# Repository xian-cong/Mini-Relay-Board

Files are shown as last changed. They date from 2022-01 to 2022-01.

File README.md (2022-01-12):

# Mini Relay Board
### Functions
This relay board is designed to be as small as possible using KiCAD to perform functions:
```
  1. Relay Switch Function (250VAC/30VDC rated voltage, 3A-5A rated current)
  2. Power Supply (5V, up to 2A) for microcontroller (e.g. Jetson Nano, Raspberry Pi, Arduino...)
  3. Push Button Input with Kill Function (i.e. IC kills the power if push button is pressed ~20secs)
  4. General Output pin (3.3V, up to 10mA) for LED/indicators
  5. SMD LED Indicator for Relay
  ```
  
### Components
Components & Datasheets can be found [here](https://github.com/xian-cong/mini-relay-board/blob/main/Components%20%26%20Datasheet.txt).

### Board Schematic
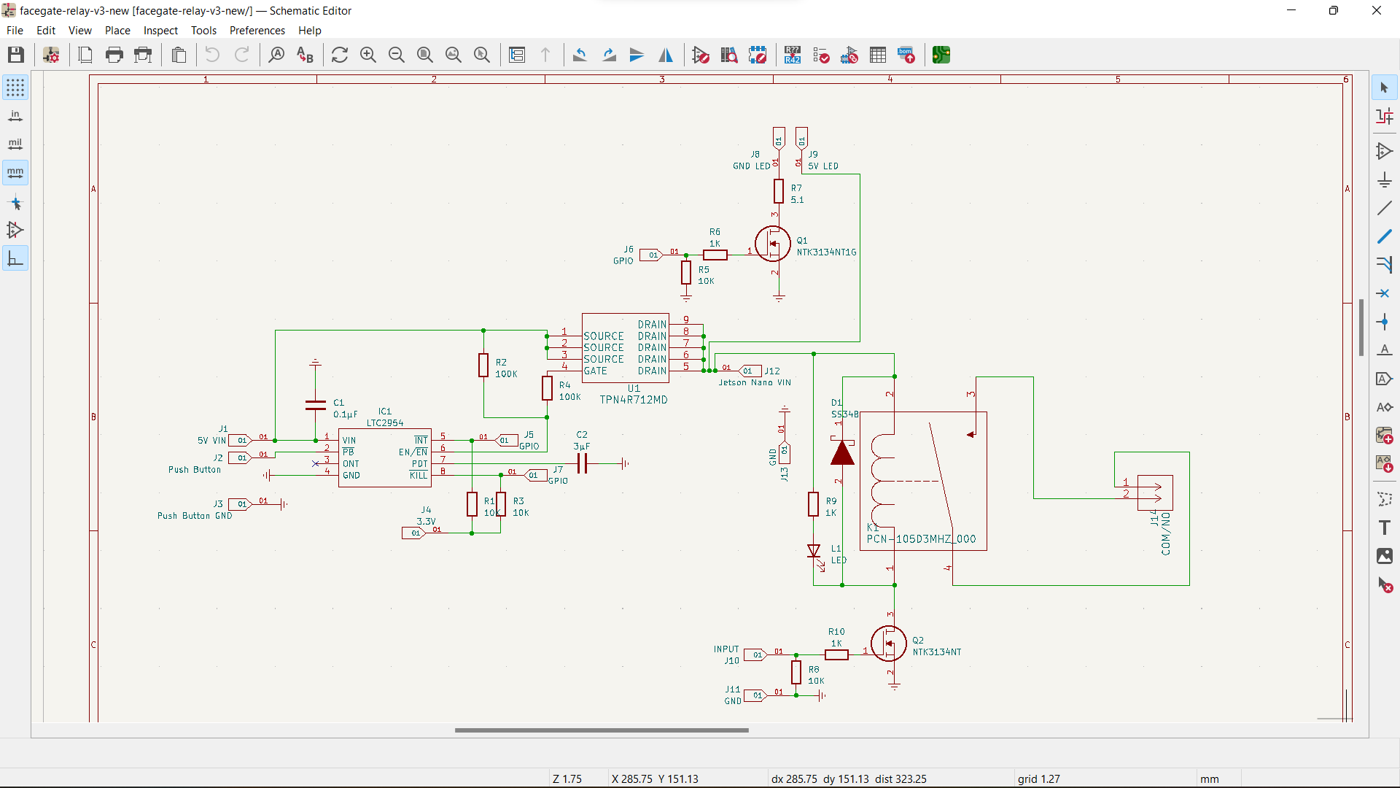
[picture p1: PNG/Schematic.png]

 
### Board Layout
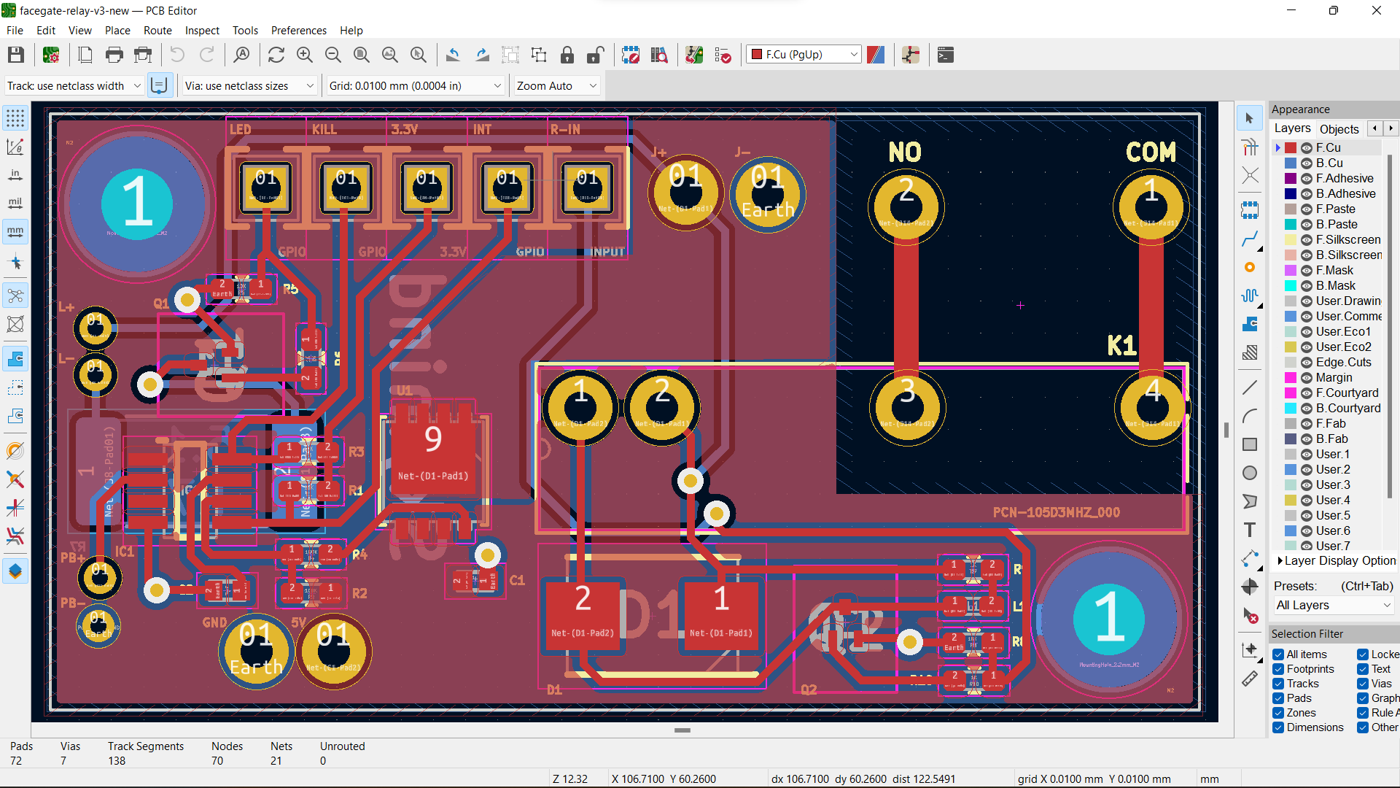
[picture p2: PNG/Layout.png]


### 3D View of Board
**Top View** <br />
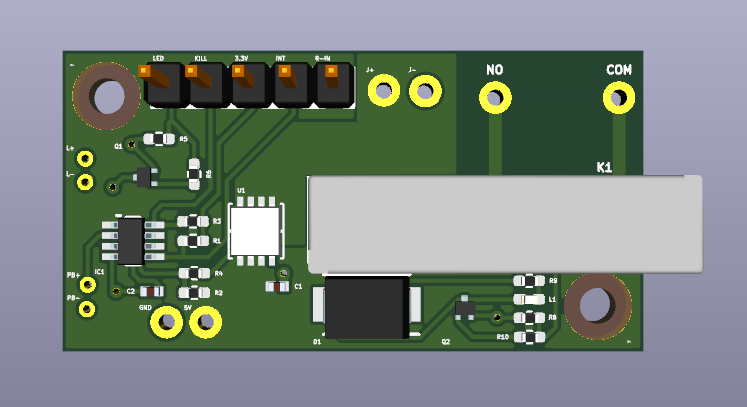
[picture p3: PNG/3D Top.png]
 <br />
**Isometric View** <br />
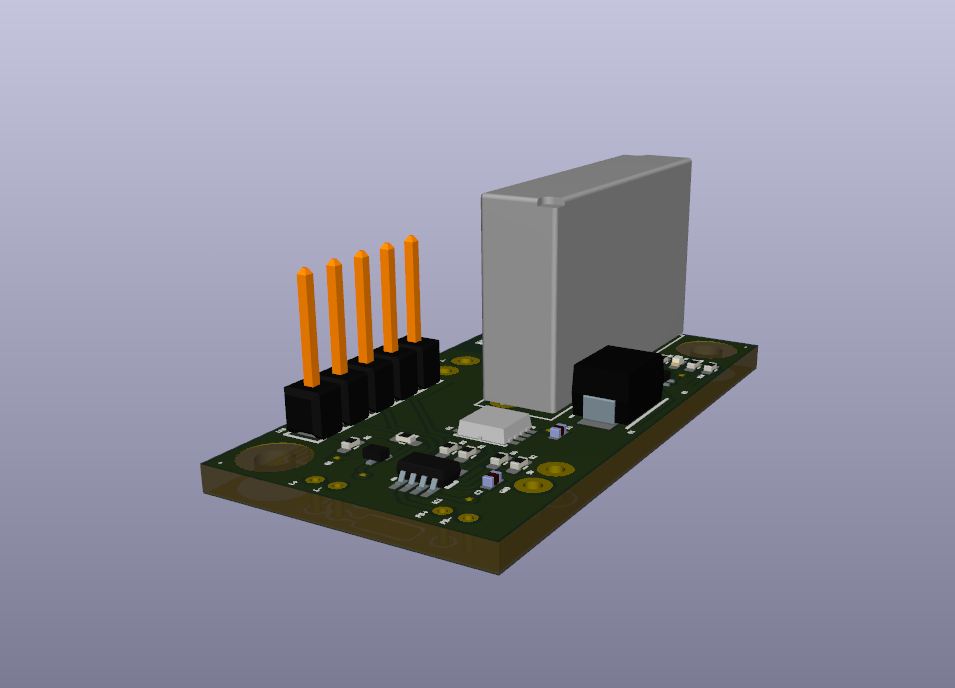
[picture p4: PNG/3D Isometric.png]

 
### Deployment View of Board
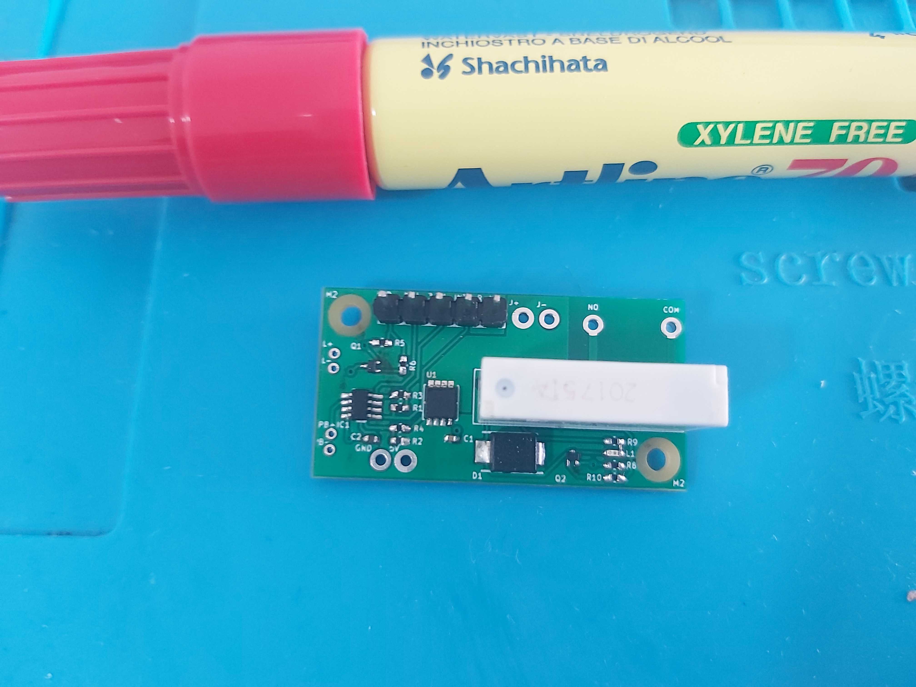
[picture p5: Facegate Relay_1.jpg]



### Board without Components


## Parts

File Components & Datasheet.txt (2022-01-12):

Relay:
https://www.digikey.my/product-detail/en/te-connectivity-potter-brumfield-relays/PCN-105D3MHZ-000/PCN-105D3MHZ000-ND/1427537
Datasheet: 
https://www.te.com/commerce/DocumentDelivery/DDEController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

Mosfet(N):
https://www.digikey.my/product-detail/en/on-semiconductor/NTK3134NT5G/2156-NTK3134NT5G-OS-ND/13457296

LED:
https://www.digikey.my/product-detail/en/kingbright/APHHS1005CGCK/754-1101-2-ND/1747499

Diode:
https://www.digikey.my/product-detail/en/mdd/SS34B/3372-SS34BTR-ND/14288057

ON/OFF IC:
https://www.analog.com/media/en/technical-documentation/data-sheets/2954fb.pdf

Mosfet(P):
https://www.digikey.my/product-detail/en/toshiba-semiconductor-and-storage/TPN4R712MD-L1Q/TPN4R712MDL1QCT-ND/5323105

Capacitor 0.1uF:
https://www.digikey.my/product-detail/en/kemet/C0402C104K7PAC7867/399-14871-1-ND/7382420

Capacitor 3uF:
https://www.digikey.my/product-detail/en/taiyo-yuden/AMK105BJ335MV-F/587-2236-6-ND/2003027

LED resistor:
https://www.digikey.my/product-detail/en/panasonic-electronic-components/ERJ-2GEJ5R1X/P5-1JCT-ND/282381
1k resistor:
https://www.digikey.my/product-detail/en/yageo/RC0402JR-071KL/311-1-0KJRCT-ND/729355

10k resistor:
https://www.digikey.my/product-detail/en/yageo/RC0402JR-0710KL/311-10KJRCT-ND/729365

100k resistor:
https://www.digikey.my/product-detail/en/yageo/RC0402FR-07100KL/311-100KLRCT-ND/729473

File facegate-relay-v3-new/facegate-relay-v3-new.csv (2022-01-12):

Id | Designator | Package | Quantity | Designation | Supplier and ref
1 | NO | ED120&slash_2DS | 1 | COM
2 | R4,R6 | R_0402_1005Metric | 2 | 100K
3 | C2 | CAPC1005X55N | 1 | 3μF
4 | K1 | PCN-105D3MHZ_000 | 1 | PCN-105D3MHZ_000
5 | Q1 | NTK3134NT1G | 1 | NTK3134NT
6 | C1 | CAPC1005X55N | 1 | 0.1μF
7 | R5,R3 | R_0402_1005Metric | 2 | 10K
8 | R7,R2,R1 | R_0402_1005Metric | 3 | 1K
9 | D1 | DIOM5336X320N | 1 | SS34B
10 | L1 | LED_0402_1005Metric | 1 | LED
11 | PB | SAMTEC_MTMM-101-06-S-S-200 | 1 | Push Button
12 | J-VIN | SAMTEC_MTMM-101-06-S-S-200 | 1 | Jetson Nano VIN
13 | Q2 | NTK3134NT1G | 1 | NTK3134NT1G
14 | U1 | TPN4R712MD | 1 | TPN4R712MD
15 | IC1 | SOT65P280X100-8N | 1 | LTC2954
16 | KILL,LED,INT | SAMTEC_MTMM-101-06-S-S-200 | 3 | GPIO
17 | 3.3V | SAMTEC_MTMM-101-06-S-S-200 | 1 | 3.3V
18 | 5V-IN | SAMTEC_MTMM-101-06-S-S-200 | 1 | 5V VIN
19 | LED | SAMTEC_MTMM-101-06-S-S-200 | 1 | 3.3V LED
20 | M2,M2 | MountingHole_2.2mm_M2 | 2 | MountingHole_2.2mm_M2
21 | 5V-GND,GND | SAMTEC_MTMM-101-06-S-S-200 | 2 | GND
22 |  |  | 1
23 | R-IN | SAMTEC_MTMM-101-06-S-S-200 | 1 | INPUT
24 | 5V | SAMTEC_MTMM-101-06-S-S-200 | 1 | 5V/VCC

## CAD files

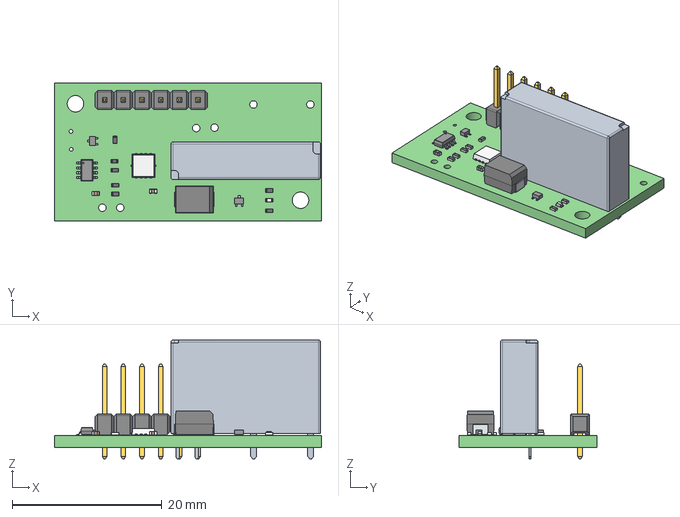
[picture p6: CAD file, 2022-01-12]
facegate-relay-v3-new/facegate-board.step
35.7 x 18.5 x 15.9 mm

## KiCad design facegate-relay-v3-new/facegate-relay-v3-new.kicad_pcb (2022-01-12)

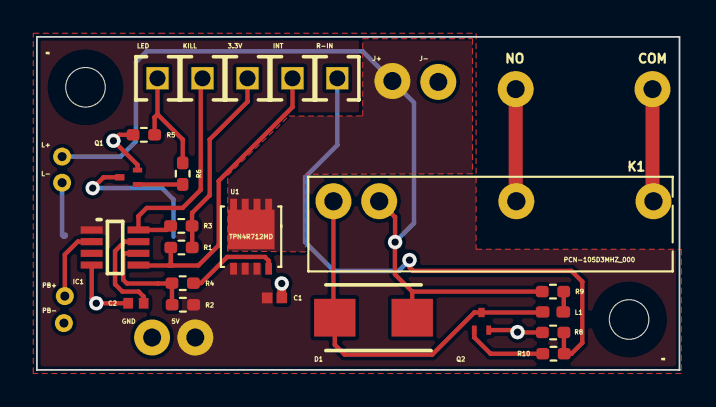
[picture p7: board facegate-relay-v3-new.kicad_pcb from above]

Board: 2 copper layers, 35.7 x 18.5 mm, 35 parts (1 on the bottom side), 20 nets.

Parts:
3.3V: 3.3V; SAMTEC_MTMM-101-06-S-S-200
5V: 5V VIN; SAMTEC_MTMM-101-06-S-S-200
C1: 0.1μF; CAPC1005X55N
C2: 3μF; CAPC1005X55N
D1: SS34B; DIOM5336X320N
GND: GND; SAMTEC_MTMM-101-06-S-S-200
IC1: LTC2954; SOT65P280X100-8N
INT: GPIO; SAMTEC_MTMM-101-06-S-S-200
J+: Jetson Nano VIN; SAMTEC_MTMM-101-06-S-S-200
J-: GND; SAMTEC_MTMM-101-06-S-S-200
K1: PCN-105D3MHZ_000
KILL: GPIO; SAMTEC_MTMM-101-06-S-S-200
L1: LED; LED_0402_1005Metric_Pad0.77x0.64mm_HandSolder
L+: 5V LED; SAMTEC_MTMM-101-06-S-S-200
L-: GND LED; SAMTEC_MTMM-101-06-S-S-200
LED: GPIO; SAMTEC_MTMM-101-06-S-S-200
M2, M2#2: MountingHole_2.2mm_M2
NO: COM; ED120&slash_2DS
PB+: Push Button; SAMTEC_MTMM-101-06-S-S-200
PB-: Push Button GND; SAMTEC_MTMM-101-06-S-S-200
Q1: NTK3134NT1G
Q2: NTK3134NT; NTK3134NT1G
R1, R3, R5, R8: 10K; R_0402_1005Metric_Pad0.72x0.64mm_HandSolder
R2, R4: 100K; R_0402_1005Metric_Pad0.72x0.64mm_HandSolder
R6, R9, R10: 1K; R_0402_1005Metric_Pad0.72x0.64mm_HandSolder
R7: 5.1; R_2512_6332Metric_Pad1.40x3.35mm_HandSolder
R-IN: INPUT; SAMTEC_MTMM-101-06-S-S-200
U1: TPN4R712MD

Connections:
Earth: C1.1, C2.2, GND.01, IC1.4 (GND), J-.01, PB-.01, Q1.2, Q2.2, R5.2, R8.2
unnamed: 5V.01, C1.2, IC1.1 (VIN), R2.1, U1.1 (SOURCE), U1.2 (SOURCE), U1.3 (SOURCE)
unnamed: C2.1, IC1.7 (PDT)
unnamed: D1.1, J+.01, K1.2, L+.01, R9.1, U1.5 (DRAIN), U1.6 (DRAIN), U1.7 (DRAIN), U1.8 (DRAIN), U1.9 (DRAIN)
unnamed: D1.2, K1.1, L1.1 (K), Q2.3
unnamed: IC1.2 (~PB), PB+.01
unnamed: IC1.5 (~INT), INT.01, R1.1
unnamed: IC1.6 (EN/~EN), R2.2, R4.1
unnamed: IC1.8 (~KILL), KILL.01, R3.1
unnamed: 3.3V.01, R1.2, R3.2
unnamed: LED.01, R5.1, R6.1
unnamed: L-.01, R7.1
unnamed: R8.1, R10.1, R-IN.01
unnamed: K1.4, NO.1
unnamed: K1.3, NO.2
unnamed: L1.2 (A), R9.2
unnamed: Q1.1, R6.2
unnamed: Q1.3, R7.2
unnamed: Q2.1, R10.2
unnamed: R4.2, U1.4 (GATE)
